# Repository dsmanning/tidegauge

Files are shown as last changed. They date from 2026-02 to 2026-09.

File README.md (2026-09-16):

# Remote Tide Gauge (Feather RP2040 + TTN)

This project builds a remote tide gauge using an Adafruit Feather RP2040 RFM, an RFM95 LoRa radio, and an HC-SR04 ultrasonic sensor.

The sensor is mounted at the top of a tube and measures water height inside the tube. The Feather samples once per minute, packages the reading, and sends it through LoRaWAN to The Things Network (TTN) via your local TTN gateway.

Current radio/uplink path is Arduino LMIC OTAA firmware in `arduino/ttn_otaa_lmic`.

## Hardware

- Adafruit Feather RP2040
- RFM95 LoRa radio module
- HC-SR04 ultrasonic module
- TTN gateway
- Development host: Raspberry Pi 5
- USB connection to Feather:
  - Mass storage device (for file transfer): `/dev/sda`
  - Serial console: `/dev/ttyACM0`

## Development approach

We use strict test-driven development (TDD):

1. Write a failing test first.
2. Run tests to confirm failure.
3. Implement the smallest code change to pass.
4. Re-run tests.
5. Refactor while keeping tests green.
6. Repeat in small increments.

Code is designed for testability:

- Hardware access is isolated behind interfaces/adapters.
- Core logic is pure and mockable.
- Time, I/O, and radio boundaries are injected dependencies.

## Data flow

1. Trigger measurement every 60 seconds.
2. Read distance from HC-SR04.
3. Convert distance to water height using calibration constants.
4. Build payload as signed millimeters (`int16`, big-endian).
5. Transmit payload through RFM95/LoRaWAN to TTN.
6. Log status/errors to serial for diagnostics.

## Tide Datum Calibration (Post-Install)

The device must support datum calibration after physical installation at the final site.

- Raw measurement from the ultrasonic sensor is distance from sensor-to-water surface.
- Tide height requires a site-specific datum offset that is not final until installation.
- The software should apply:
  - `tide_height = geometry_reference - measured_distance - datum_offset`
  - Where `geometry_reference` (sensor-to-reference geometry) and `datum_offset` are configurable calibration values.

Recommended calibration workflow:

1. Install and mechanically secure the sensor in final position.
2. Take one or more manual reference readings against known local tide datum.
3. Compute/update `datum_offset` (and `geometry_reference` if needed).
4. Persist calibration values in device configuration.
5. Verify reported tide height against reference observations.

TDD impact:

- Add tests first for calibration math and configuration handling.
- Verify behavior before calibration is set (safe defaults/error handling).
- Verify updated calibration changes only conversion output, not transport logic.
- Keep calibration logic in pure, testable code paths with hardware mocked.

## Testing strategy

- Host-side unit tests validate:
  - Distance-to-height conversion
  - Payload encoding
  - Scheduler behavior (1-minute cadence)
  - Error handling and retries
- Hardware integrations are wrapped so they can be replaced with mocks/fakes in tests.
- On-device validation is done only after host tests pass.

## Project status

The production path is Arduino LMIC. The older Python/CircuitPython modules are
retained for reference; their tests do not validate the deployed Arduino scheduler.
Firmware orchestration is in `arduino/ttn_otaa_lmic/src/app`, hardware adapters in
`src/adapters`, and injected contracts in `src/ports`. Pure payload/calibration
logic is in `measurement.h` and `tide_math.h`.

## Pi-to-Feather Workflow

Use this sequence for deployment and runtime verification from the Raspberry Pi host.

1. Run host tests:
   `python3 -m pytest -q`
2. Confirm device connectivity:
   `lsblk -f` and verify `/dev/sda` (mounted volume) plus `/dev/ttyACM0` (serial).
3. Compile Arduino firmware:
   - First copy/edit config:
     `cp -n arduino/ttn_otaa_lmic/config.example.h arduino/ttn_otaa_lmic/config.h`
   - Set `DEV_EUI_HEX`, `APP_EUI_HEX`, `APP_KEY_HEX`, `US915_SUBBAND`, `GEOMETRY_REFERENCE_M`, and `DATUM_OFFSET_M` in `arduino/ttn_otaa_lmic/config.h`.
   - `config.h` is git-ignored by design; keep real credentials only in that local file.
   `bash scripts/compile_firmware.sh --output-dir build/firmware`
   The build script explicitly selects US915/RFM95 and allocates **64 KB** of
   LittleFS flash for the join-nonce journal. The default board setting has no
   filesystem and cannot operate the persistent join allocator.
4. Upload Arduino firmware:
   Update the TTN decoder below first, then:
   `arduino-cli upload -b rp2040:rp2040:adafruit_feather_rfm:flash=8388608_65536 -p /dev/ttyACM0 --input-dir build/firmware arduino/ttn_otaa_lmic`
5. Monitor serial runtime logs on `/dev/ttyACM0` and verify a measurement/send cycle appears once per minute.
6. Confirm uplinks in TTN for the same time window as serial logs.

## Firmware Watchdog

The hardware watchdog is armed before startup waits and peripheral initialization.
It resets the RP2040 after **8 seconds** without a feed; unsupported delays above
8388 ms fail compilation. The prior 20-second setting was invalid for RP2040.
Ultrasonic acquisition now advances one pulse at a time (45 ms maximum blocking
wait); settling, sample gaps and temperature conversion are scheduled stages.
LMIC receives service between stages, and acquisition yields around radio deadlines.

The supervisor also detects failures that leave the CPU running: a measurement
cycle exceeding 30 seconds resets the sensor state, a second consecutive stall
reboots; a joined radio with no progress for 3 minutes restarts joining, and a
subsequent radio stall reboots. Joining receives a 30-minute progress deadline.
Deliberate retry backoff (1 minute increasing to 1 hour) does not cause reboots.
Normal join attempts count as local progress even when the gateway is offline.
Local transmit completion does not prove network reception.

Measurements start on a fixed 60-second schedule independent of radio joining.
The latest completed measurement replaces older unsent data; there is no historical
backfill. Invalid readings still produce a packet containing working fields.
Default quality requirements are at least 16 valid samples out of 64 and a
cluster of at least three. Physical echo bounds default to 0.02–6 m; customize
`TIDEGAUGE_MIN_DISTANCE_M` / `TIDEGAUGE_MAX_DISTANCE_M` in local configuration.
After three temperature failures the bus is rediscovered and reconfigured.

ADR owns transmit power while enabled; the configured 10 dBm value applies only
when ADR is disabled. LMIC link recovery is enabled. Verify link margin at the
installed location and calculate airtime for the actual data rate; sampling once
per minute need not imply that every network permits transmitting that often.

Validated toolchain: Arduino CLI 1.4.1, Arduino-Pico 5.5.0, MCCI LMIC 5.0.1,
OneWire 2.3.8, DallasTemperature 4.0.6. Host checks use pytest, g++, Node.js,
PyYAML and Jinja2 already present on the development host. Build/test commands
do not install dependencies. Physical acceptance procedures and remaining
limitations are in [docs/reliability-validation.md](docs/reliability-validation.md).

## TTN Credentials (Arduino LMIC)

Set OTAA credentials in `arduino/ttn_otaa_lmic/config.h`:

- `DEV_EUI_HEX`
- `APP_EUI_HEX`
- `APP_KEY_HEX`
- `US915_SUBBAND`: human numbering **1–8**, converted to LMIC **0–7**. Value `2`
  selects channels 8–15 (LMIC index 1). Confirm against the gateway frequency plan.

Invalid credential syntax disables radio operation while sampling continues.
Channel fallback visits every group and returns to the preferred group.

Join nonces are reserved in blocks of 32 in `/join-nonce.bin` before use, using
an atomic LittleFS replacement and read-back verification. Reboots skip unused
reserved nonces. Preserve this filesystem and its allocation when updating
firmware; never erase it for ordinary recovery. Only a completely blank allocated
region is formatted automatically. Missing allocation, corrupt storage, failed
writes, or exhausted 16-bit nonce space stop joins with a serial error, rather
than silently reusing nonces. These faults require maintenance, not reboot loops.
First migration from the old random-nonce firmware must be checked against TTN's
stored nonce history and configured LoRaWAN version. Do not disable replay
protection to make joins succeed; coordinate reprovisioning if necessary.

## TTN Payload Formatter

Use `ttn/uplink_decoder.js` as the TTN JavaScript uplink payload formatter.

Normal uplinks on FPort 1 retain the 10-byte payload:

- Bytes `0-1`: `tide_height_mm` (signed int16, big-endian)
- Bytes `2-3`: `raw_distance_mm` (unsigned uint16, big-endian)
- Bytes `4-5`: `battery_mv` (unsigned uint16, big-endian)
- Bytes `6-7`: `distance_stddev_mm` (unsigned uint16, big-endian)
- Bytes `8-9`: `temperature_centi_c` (signed int16, big-endian)

Invalid optional measurements use sentinel values so one failed sensor reading
does not block the whole uplink:

- signed invalid sentinel: `0x8000`
- unsigned invalid sentinel: `0xFFFF`

Battery now also uses `0xFFFF` for unavailable, decoded as `null`.
The first queued packet and every 15th thereafter attempt a diagnostic extension
on FPort 2: **26 bytes** total, with the same first 10 bytes. Deploy the new decoder
before the firmware. If the current data rate cannot carry the extension, the
radio sends the 10-byte measurement at that data rate; diagnostic details may
therefore be unavailable on a weak link.

| Bytes | Diagnostic field (big-endian) |
| --- | --- |
| 10 | Schema version: 1 |
| 11 | Fault bits: 0 height, 1 temperature, 2 battery, 3 echo stuck high |
| 12 | Reset reason: 0 other/power-on, 1 sensor stall, 2 radio stall, 3 watchdog/other watchdog reset |
| 13 | Firmware revision: 2 |
| 14–17 | Uptime seconds (continues across `millis()` rollover) |
| 18–19 | Recovery count since boot |
| 20–21 | Valid echo count, timeout count |
| 22–23 | Watchdog reset count retained across watchdog resets; clears on cold start |
| 24–25 | Measurement sequence modulo 65536 |

## Home Assistant Filtering

The optional Home Assistant configuration in `homeassistant/tide_gauge_filter.yaml`
adds a post-TTN filtering pipeline for the decoded tide-height sensor.

Its purpose is to clean occasional ultrasonic outliers while preserving the slow
water-level trend:

1. hold the last valid numeric reading
2. compute a 10-minute rolling median
3. reject remaining outlier values outside recent history
4. apply light low-pass smoothing

This filter runs in Home Assistant, not on the RP2040. It should be merged into
an existing Home Assistant configuration carefully if that installation already
has top-level `template:` or `sensor:` sections.

Add `homeassistant/tide_gauge_freshness.yaml` to track last packet, last valid
height, and last valid temperature separately. It requires the actual TTN uplink
MQTT topic bridged into Home Assistant's broker; replace the placeholder topic
and merge the template lists. No account connection is configured by this repo.
Stale indicators turn on after five minutes without the relevant report, even
if filtering retains an old value. Use `sensor.tide_height_current` for the
freshness-gated dashboard reading. The templates use the server's `received_at`
timestamp, not MQTT replay/arrival time. See the official
[MQTT trigger documentation](https://www.home-assistant.io/docs/automation/templating/)
and [template integration](https://www.home-assistant.io/integrations/template).

## Sensor Wiring And Calibration

### Payload compatibility

The TTN decoder accepts the deployed 10-byte measurement payload, the compact
11-byte session-marker payload, the earlier 12-byte sequence payload, and the
26-byte diagnostic payload produced by firmware revision 2. For 11-byte
payloads, byte 10 uses bit 7 as `session_start` and bits 0–6 as the rolling
sample sequence. For 12-byte payloads, bytes 10–11 contain the sequence as an
unsigned big-endian integer. Keep the decoder installed before changing the
firmware payload format.

### Electrical safety

The HC-SR04 is powered from 5V. Its ECHO output must pass through a level
shifter or resistor divider before reaching RP2040 D5; never connect a 5V ECHO
signal directly to the RP2040. The DS18B20 data line uses D9 with a 4.7k pullup
to 3.3V.

HC-SR04 pinout (Feather labels):

- `TRIG` -> `D6`
- `ECHO` -> `D5`
- `VCC` -> `5V`
- `GND` -> `GND`

Firmware calibration constants are in `arduino/ttn_otaa_lmic/config.h`:

- `DISTANCE_SCALE`
- `DISTANCE_OFFSET_M`
- `GEOMETRY_REFERENCE_M`
- `DATUM_OFFSET_M`

Conversion formula:
`corrected_distance_m = measured_distance_m * distance_scale + distance_offset_m`
`tide_height_m = geometry_reference_m - corrected_distance_m - datum_offset_m`

Important electrical note:
`HC-SR04 ECHO` is a 5V signal and must be level-shifted (or resistor-divided) before feeding RP2040 `D5` (3.3V-only input).

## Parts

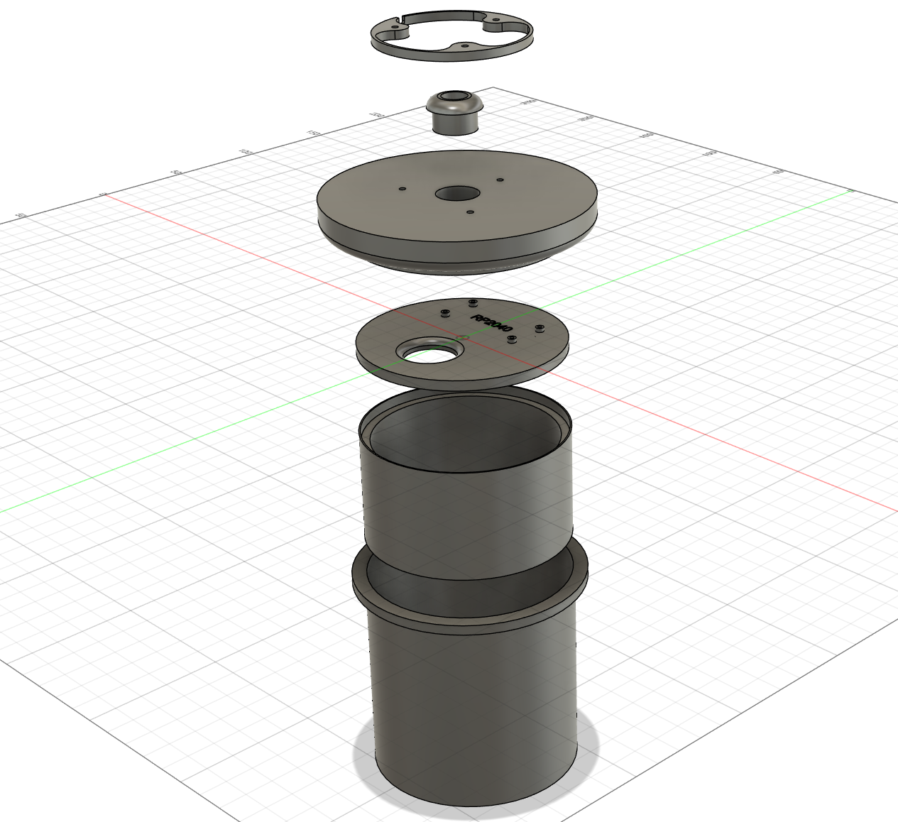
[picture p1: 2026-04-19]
stl/Tide Gauge - Assembly of 3D Printed Parts.png

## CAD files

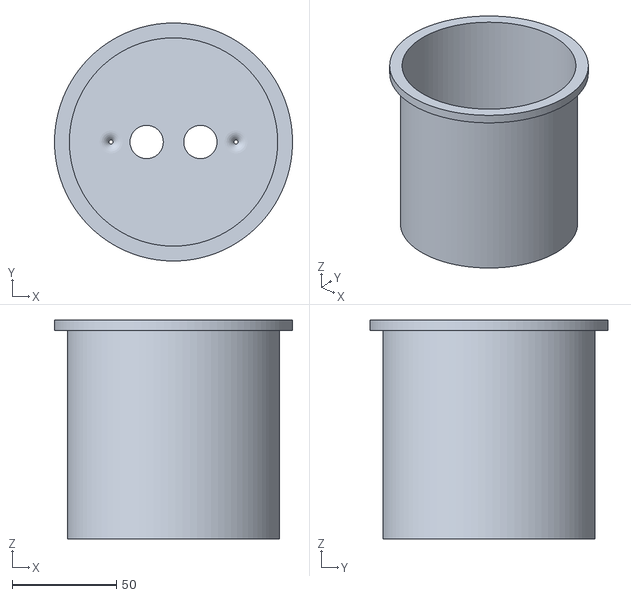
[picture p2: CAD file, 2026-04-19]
stl/Tide Gauge Mount - Outer Body - HC-SR04.stl
114.3 x 114.3 x 105.0

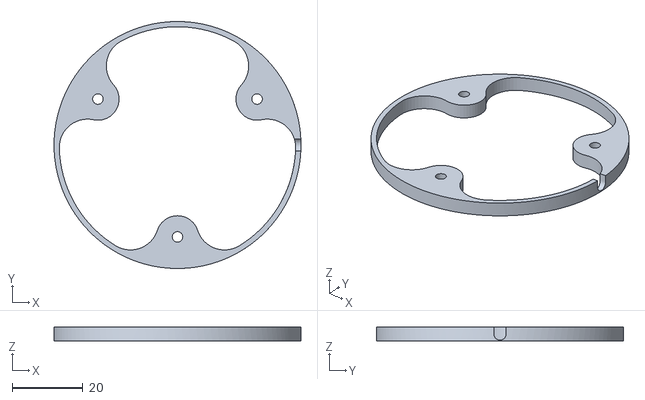
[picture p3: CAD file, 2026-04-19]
stl/Tide Gauge Mount - Top Ring - 10W.stl
70.0 x 70.0 x 4.00

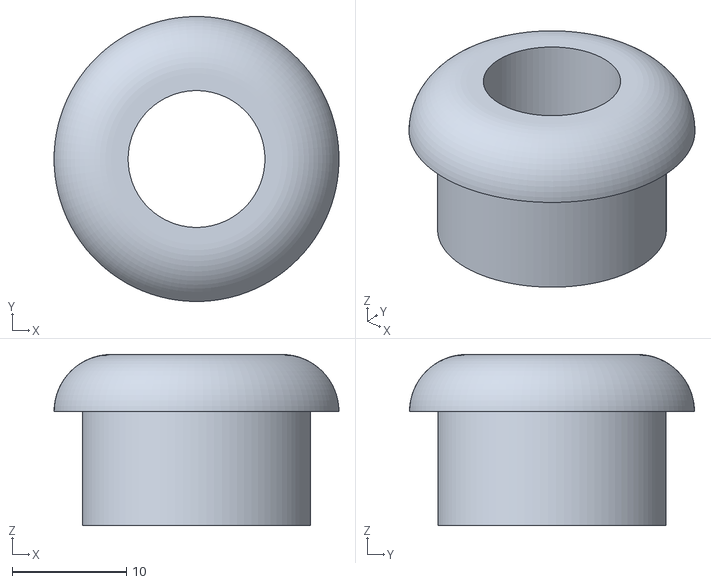
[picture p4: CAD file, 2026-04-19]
stl/Tide Gauge Mount - Top Plug.stl
25.0 x 25.0 x 15.0

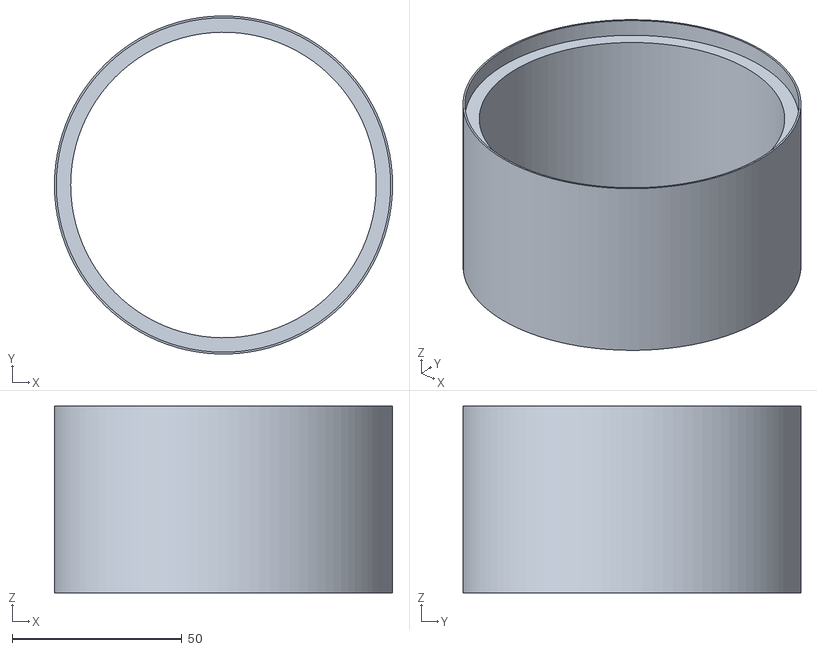
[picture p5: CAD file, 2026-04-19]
stl/Tide Gauge Mount - Bottom Support Ring.stl
99.6 x 99.6 x 55.0

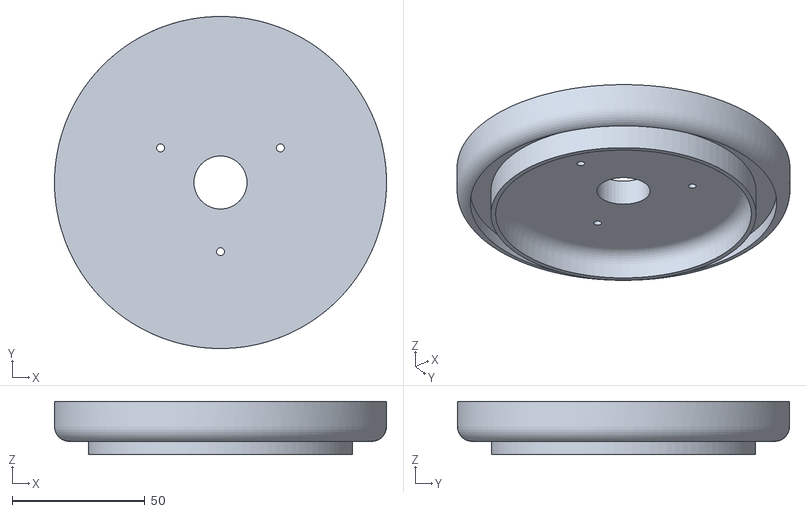
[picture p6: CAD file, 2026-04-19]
stl/Tide Gauge Mount - Top - 10W.stl
125.0 x 125.0 x 20.0

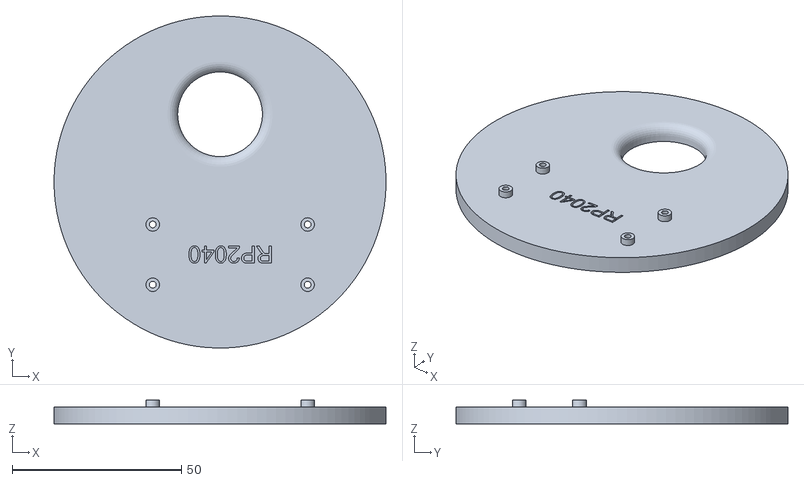
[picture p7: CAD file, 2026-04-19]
stl/Tide Gauge Mount - Middle Part.stl
98.0 x 98.0 x 7.00

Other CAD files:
stl/Tide Gauge Mount - Outer Body JSN-SR04T.stl

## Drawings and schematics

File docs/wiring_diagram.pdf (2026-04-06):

# Remote Tide Gauge Circuit Diagram

## Emitter

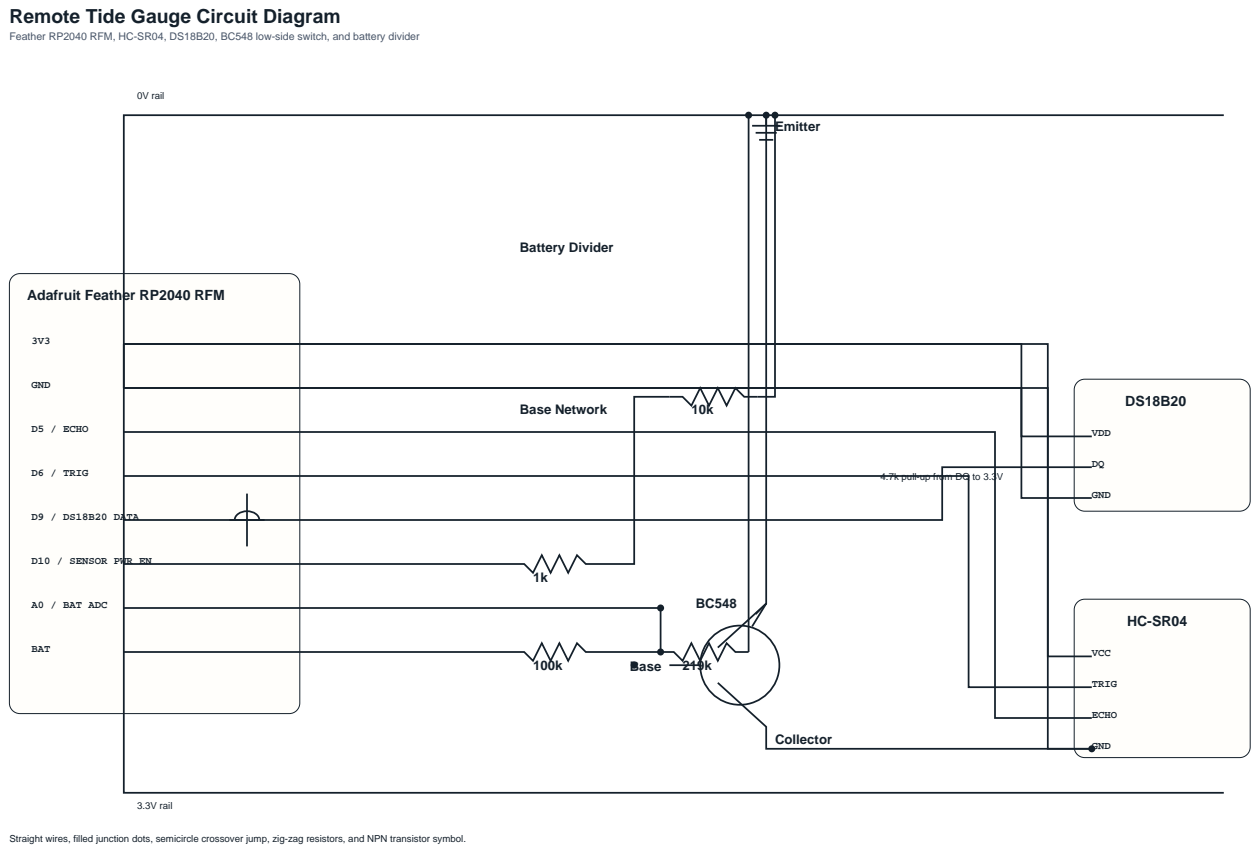
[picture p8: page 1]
GND; D5 / ECHO; D6 / TRIG; D9 / DS18B20 DATA; A0 / BAT ADC; BAT; VCC; TRIG; ECHO; VDD; 3.3V rail; 0V rail; Base Network; Base; Collector; Battery Divider

Feather RP2040 RFM, HC-SR04, DS18B20, BC548 low-side switch, and battery divider

Adafruit Feather RP2040 RFM

4.7k pull-up from DQ to 3.3V

D10 / SENSOR PWR EN

Straight wires, filled junction dots, semicircle crossover jump, zig-zag resistors, and NPN transistor symbol.

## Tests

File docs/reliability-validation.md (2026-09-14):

# Unattended-node acceptance

Host tests and a successful compile do not establish that a radio, sensor power
switch, supply, or enclosure will recover in the field. Complete these checks
on the real Feather before installing it somewhere inaccessible.

## Build and migration

Use `bash scripts/compile_firmware.sh --output-dir build/firmware` with the
versions recorded in README. This pins regional compilation flags for both C
and C++, rather than relying on edits inside an installed LMIC library.
Keep local `config.h`, binaries, and TTN credentials out of git.

Verify US915 group 2 means LMIC index 1 and matches the actual gateway channel
plan. Confirm TTN MAC/PHY settings match the installed LMIC version. Firmware
does not become LoRaWAN 1.0.4/1.1 merely by using persistent nonces.

Install the new TTN decoder before firmware revision 2. Reserve the documented
64 KB filesystem and preserve it on future uploads. On first migration, check
TTN join events for previously used/non-increasing DevNonce errors: the old
firmware used random nonces and this release cannot infer the server's history.
If necessary, plan credential/device reprovisioning before field installation.
Do not erase the journal or weaken replay checks as an unattended workaround.

## Fault-injection acceptance

| Test | Required observation |
| --- | --- |
| Cold boot without USB console | Joins and reports without waiting indefinitely for serial |
| MCU stall in an isolated test build | Hardware reset within about 8 seconds; diagnostic reset reason 3 |
| Suppressed TX-complete event in test build | Radio recovery after about 3 minutes; samples continue |
| Radio progress remains absent after recovery | Reboot after join grace period, with reason 2 |
| Gateway off for several hours, then restored | Bounded join retries; no rapid reboot loop; reports resume |
| Echo disconnected or held high | Invalid height, timeout/echo flags; temperature and battery still transmit |
| Temperature sensor absent at boot, then reattached | Discovery retry restores temperature within roughly four sample cycles |
| Power interrupted during a nonce reservation | Next boot never reuses a nonce emitted before interruption |
| Corrupt nonce file (bench copy only) | Joining stops with explicit storage error; no autoformat |
| Weak radio link / lowest data rate | Measurements continue even when diagnostic extension does not fit |
| No MQTT packets for five minutes | Link and data stale; dashboard current height becomes unavailable |
| Packets with invalid height but valid temperature | Link remains current; height becomes stale independently |

Run a minimum 72-hour soak with the final wiring, battery supply, sensors,
enclosure and antenna. Include gateway outage/recovery, repeated sensor faults,
and cold starts. Inspect TTN frame counters, join failures, uplink spacing,
diagnostic resets and sample quality. Host simulations cover clock rollover,
long outages and failure escalation, but do not replace these measurements.

## Electrical checks

Measure supply voltage during radio TX and sensor startup; a healthy unloaded
battery does not establish adequate transient supply margin. Confirm echo level
shifting and pull-ups, power-switch polarity, a safe sensor-off state during MCU
reset, and actual sensor rail discharge when switched off. Inspect moisture
protection and cable strain relief. Verify radio reset wiring.

If a fault survives MCU and radio reset, evaluate an independent supervisor
that cycles power to the entire node with controlled backoff. That is a hardware
change requiring bench validation; it is not supplied by firmware alone.

## Operational limits

Only the latest measurement is queued, not an outage history. Diagnostic packets
are unconfirmed and can be lost, particularly at low data rates. A local TX
completion proves the radio cycle ended, not gateway/cloud reception. Persistent
nonce ranges consume 32 values per cold/recovery boot at minimum and eventually
exhaust the 16-bit namespace; avoid periodic gratuitous rebooting and monitor
join failures. The stored reset counter is retained SRAM, not a lifetime count.

Compute daily airtime at the deployed data rate, including joins and status
packets. TTN Community's fair-use allowance is 30 seconds uplink airtime/day and
10 downlinks/day. A private gateway connected to the community network does not
remove that allowance. If necessary, keep minute sampling but batch or reduce
transmissions as a separately tested site policy. See
[TTN duty-cycle and fair-use guidance](https://www.thethingsnetwork.org/docs/lorawan/duty-cycle/).

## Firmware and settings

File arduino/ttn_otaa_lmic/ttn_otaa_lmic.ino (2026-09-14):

#include <Arduino.h>
#include <SPI.h>
#include <pico/time.h>
#include <hardware/watchdog.h>
#include <OneWire.h>
#include <DallasTemperature.h>
#include <lmic.h>
#include <hal/hal.h>
#if __has_include("config.h")
#include "config.h"
#else
#include "config.example.h"
#endif
#include "runtime_config.h"
#include "src/app/node_runtime.h"
#include "src/adapters/arduino_sensor.h"
#include "src/adapters/lmic_radio.h"
#include "src/adapters/nonce_storage.h"

static_assert(tg_config::US915_SUBBAND >= 1 && tg_config::US915_SUBBAND <= 8, "Subband must be 1..8");
static_assert(tg_config::ULTRASONIC_SAMPLE_COUNT >= 3 && tg_config::ULTRASONIC_SAMPLE_COUNT <= 100, "Sample count must be 3..100");
static_assert(tg_config::ULTRASONIC_TIMEOUT_US > 0 && tg_config::ULTRASONIC_TIMEOUT_US <= 45000, "Echo deadline must be <=45ms");
static_assert(tg_config::ULTRASONIC_POWER_SETTLE_MS <= 5000 && tg_config::ULTRASONIC_INTERSAMPLE_DELAY_MS <= 100, "Sensor cycle must fit 30s deadline");
static_assert(tg_config::DS18B20_RESOLUTION_BITS >= 9 && tg_config::DS18B20_RESOLUTION_BITS <= 12, "DS18B20 resolution must be 9..12");
static_assert(tg_config::IDLE_LOOP_SLEEP_MS <= 10, "LMIC must be serviced frequently");
static_assert(tg_config::RAPID_DIAGNOSTIC_INTERVAL_S > 0, "Sampling interval must be positive");
static_assert(TIDEGAUGE_MIN_DISTANCE_M > 0 && TIDEGAUGE_MAX_DISTANCE_M > TIDEGAUGE_MIN_DISTANCE_M, "Invalid sensor range");

static uint8_t APPEUI[8], DEVEUI[8], APPKEY[16];
static const int HCSR04_TRIG_PIN = D6;
static const int HCSR04_ECHO_PIN = D5;
static const int HCSR04_POWER_ENABLE_PIN = tg_config::ULTRASONIC_POWER_ENABLE_PIN;
static const int BATTERY_ADC_PIN = 26;
static const float BATTERY_DIVIDER_RATIO = 1.545f;
static OneWire g_one_wire(tg_config::DS18B20_DATA_PIN);
static DallasTemperature g_temperature_sensors(&g_one_wire);
static tidegauge::SubbandFallback g_subband_fallback(tg_config::US915_SUBBAND);
static osjob_t sendjob;

void os_getArtEui(u1_t* buf) {memcpy(buf,APPEUI,8);}
void os_getDevEui(u1_t* buf) {memcpy(buf,DEVEUI,8);}
void os_getDevKey(u1_t* buf) {memcpy(buf,APPKEY,16);}
const lmic_pinmap lmic_pins = {
    .nss=PIN_RFM_CS, .rxtx=LMIC_UNUSED_PIN, .rst=PIN_RFM_RST,
    .dio={PIN_RFM_DIO0,PIN_RFM_DIO1,PIN_RFM_DIO2},
};

class ArduinoClock : public tidegauge::ClockPort {
    uint32_t now_ms() override {return millis();}
};
class HardwareWatchdog : public tidegauge::WatchdogPort {
public:
    void feed() override {watchdog_update();}
    void reboot(uint8_t reason) override {
        watchdog_hw->scratch[2]=reason;
        watchdog_reboot(0,0,0);
        while(true) {} // Do not feed after requesting recovery.
    }
};
static ArduinoClock g_clock;
static HardwareWatchdog g_watchdog;
static tidegauge::LittleFsNonceStorage g_storage;
static tidegauge::JoinNonce g_nonce(g_storage);
static tidegauge::LmicRadio g_radio(g_clock,g_nonce,g_subband_fallback,
    tg_config::LORA_ADR_ENABLED,tg_config::LORA_UPLINK_TX_POWER_DBM);
static tidegauge::ArduinoSensor g_sensor_hardware(g_temperature_sensors,
    HCSR04_TRIG_PIN,HCSR04_ECHO_PIN,HCSR04_POWER_ENABLE_PIN,BATTERY_ADC_PIN,
    BATTERY_DIVIDER_RATIO,tg_config::ULTRASONIC_TIMEOUT_US,tg_config::DS18B20_RESOLUTION_BITS);

static tidegauge::SensorSettings sensor_settings() {
    tidegauge::SensorSettings s;
    s.samples=tg_config::ULTRASONIC_SAMPLE_COUNT;
    s.minimum_valid=s.samples/4>3 ? s.samples/4 : 3;
    s.settle_ms=HCSR04_POWER_ENABLE_PIN>=0 ? tg_config::ULTRASONIC_POWER_SETTLE_MS : 0;
    s.gap_ms=tg_config::ULTRASONIC_INTERSAMPLE_DELAY_MS;
    s.speed=tg_config::SPEED_OF_SOUND_M_PER_US;
    s.scale=tg_config::DISTANCE_SCALE; s.offset=tg_config::DISTANCE_OFFSET_M;
    s.reference=tg_config::GEOMETRY_REFERENCE_M; s.datum=tg_config::DATUM_OFFSET_M;
    s.min_distance=TIDEGAUGE_MIN_DISTANCE_M; s.max_distance=TIDEGAUGE_MAX_DISTANCE_M;
    return s;
}
static tidegauge::SensorCycle g_sensor(g_sensor_hardware,sensor_settings());
static tidegauge::NodeRuntime g_node(g_clock,g_sensor,g_radio,g_watchdog,
    tg_config::RAPID_DIAGNOSTIC_MODE ? tg_config::RAPID_DIAGNOSTIC_INTERVAL_S*1000 : 60000,
    tg_config::RAPID_DIAGNOSTIC_MODE);

static bool hex_to_bytes(const char* hex,uint8_t* out,size_t count) {
    if(strlen(hex)!=count*2) return false;
    for(size_t i=0;i<count;++i) {
        uint8_t value=0;
        for(unsigned j=0;j<2;++j) {
            const char c=hex[i*2+j];
            const int digit=c>='0' && c<='9' ? c-'0' :
                c>='a' && c<='f' ? c-'a'+10 : c>='A' && c<='F' ? c-'A'+10 : -1;
            if(digit<0) return false;
            value=static_cast<uint8_t>((value<<4)|digit);
        }
        out[i]=value;
    }
    return true;
}
static void reverse_bytes(uint8_t* bytes,size_t size) {
    for(size_t i=0;i<size/2;++i) {uint8_t b=bytes[i]; bytes[i]=bytes[size-1-i]; bytes[size-1-i]=b;}
}

// Never autoformat a damaged filesystem: losing the nonce journal permits reuse.
// Formatting is allowed only on a completely erased, allocated FS region.
extern uint8_t _FS_start, _FS_end;
static bool mount_nonce_storage() {
    const uintptr_t start=reinterpret_cast<uintptr_t>(&_FS_start);
    const uintptr_t end=reinterpret_cast<uintptr_t>(&_FS_end);
    if(end<=start || end-start<65536) return false;
    LittleFS.setConfig(LittleFSConfig(false));
    if(LittleFS.begin()) return true;
    for(uintptr_t address=start;address<end;++address) {
        if(*reinterpret_cast<const uint8_t*>(address)!=0xff) return false;
    }
    return LittleFS.format() && LittleFS.begin();
}

static void do_send(osjob_t*) {
    g_node.tick();
    static uint32_t logged=0;
    if(logged!=g_node.measurements) {
        logged=g_node.measurements;
        // Logging is best-effort and only after a completed measurement.
        if(Serial && Serial.availableForWrite()>=48) {
            Serial.print("MEASURE: height="); Serial.print(g_node.latest.height,3);
            Serial.print(" temperature_c="); Serial.println(g_node.latest.temperature,2);
        }
    }
}
void onEvent(ev_t event) {
    g_radio.on_event(event);
    if(Serial && Serial.availableForWrite()>=32) {
        Serial.print("LMIC event="); Serial.println(static_cast<unsigned>(event));
    }
}

void setup() {
    const bool watchdog_boot=watchdog_caused_reboot();
    const uint32_t magic=0x54474432;
    if(watchdog_boot && watchdog_hw->scratch[0]==magic) {
        g_node.watchdog_boots=static_cast<uint16_t>(watchdog_hw->scratch[1]+1);
        g_node.reset_reason=watchdog_hw->scratch[2] ? watchdog_hw->scratch[2] : 3;
    } else {
        g_node.watchdog_boots=watchdog_boot ? 1 : 0;
        g_node.reset_reason=watchdog_boot ? 3 : 0;
    }
    watchdog_hw->scratch[0]=magic;
    watchdog_hw->scratch[1]=g_node.watchdog_boots;
    watchdog_hw->scratch[2]=0;
    watchdog_enable(TIDEGAUGE_WATCHDOG_TIMEOUT_MS, true);
    Serial.begin(115200);
    while (!Serial && millis()<3000) {}
    if(watchdog_boot) Serial.println("WATCHDOG: reboot detected");
    Serial.println("Tide gauge firmware 2 starting");

    pinMode(HCSR04_TRIG_PIN,OUTPUT); pinMode(HCSR04_ECHO_PIN,INPUT);
    if(HCSR04_POWER_ENABLE_PIN>=0) pinMode(HCSR04_POWER_ENABLE_PIN, OUTPUT);
    g_sensor.reset(); digitalWrite(HCSR04_TRIG_PIN,LOW); analogReadResolution(12);
    watchdog_update();
    const bool credentials_ok=hex_to_bytes(tg_config::APP_EUI_HEX,APPEUI,sizeof(APPEUI)) &&
        hex_to_bytes(tg_config::DEV_EUI_HEX,DEVEUI,sizeof(DEVEUI)) &&
        hex_to_bytes(tg_config::APP_KEY_HEX,APPKEY,sizeof(APPKEY));
    if(!credentials_ok) {
        Serial.println("Invalid credentials: radio disabled; sampling continues");
    }
    reverse_bytes(APPEUI,sizeof(APPEUI)); reverse_bytes(DEVEUI,sizeof(DEVEUI));
    if (tg_config::RAPID_DIAGNOSTIC_MODE) {
        Serial.println("DIAG: skipping LoRa join");
        do_send(&sendjob);
        return;
    }
    g_storage.set_ready(credentials_ok && mount_nonce_storage());
    watchdog_update();
    os_init();
    watchdog_update();
    g_radio.begin();
}

void loop() {
    if(!tg_config::RAPID_DIAGNOSTIC_MODE) {
        g_radio.service();
        os_runloop_once();
    }
    do_send(&sendjob);
    static bool storage_error_logged=false;
    if(g_radio.storage_failed() && !storage_error_logged && Serial) {
        Serial.println("NONCE: storage unavailable/corrupt/exhausted; radio disabled");
        storage_error_logged=true;
    }
    sleep_ms(tg_config::IDLE_LOOP_SLEEP_MS);
}

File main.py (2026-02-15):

from tidegauge.main import run_main


TRIGGER_PIN_ID = 6
ECHO_PIN_ID = 5
CALIBRATION_PATH = "/calibration.json"
MEASUREMENT_INTERVAL_S = 60
MAX_SEND_ATTEMPTS = 3


def create_lora_client(
    *,
    driver_factory=None,
    credentials_loader=None,
):
    """Return configured LoRaWAN client for the board."""
    from tidegauge.adapters.lorawan_client import LoRaWanClientAdapter

    if driver_factory is None:
        from tidegauge.adapters.feather_lorawan import create_feather_lorawan_driver

        driver_factory = create_feather_lorawan_driver

    if credentials_loader is None:
        from tidegauge.ttn_credentials import load_ttn_credentials

        credentials_loader = load_ttn_credentials

    credentials = credentials_loader()
    return LoRaWanClientAdapter(driver=driver_factory(credentials=credentials))


def main() -> int:
    import board
    import digitalio
    import time
    from tidegauge.adapters.circuitpython_compat import (
        CircuitPythonTimeModule,
        create_machine_compat_module,
    )

    machine_module = create_machine_compat_module(
        board_module=board,
        digitalio_module=digitalio,
    )
    time_module = CircuitPythonTimeModule(time_module=time)

    return run_main(
        machine_module=machine_module,
        time_module=time_module,
        lora_client=create_lora_client(),
        trigger_pin_id=TRIGGER_PIN_ID,
        echo_pin_id=ECHO_PIN_ID,
        calibration_path=CALIBRATION_PATH,
        measurement_interval_s=MEASUREMENT_INTERVAL_S,
        max_send_attempts=MAX_SEND_ATTEMPTS,
    )


if __name__ == "__main__":
    main()

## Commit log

2026-02-15 Document post-install tide datum calibration in README
2026-02-15 Add initial tide-height calibration function with test
2026-02-15 Validate ultrasonic distance while allowing negative tide height
2026-02-15 Add calibration config model with explicit uncalibrated state
2026-02-15 Add TTN payload encoder for signed millimeter tide height
2026-02-15 Add sensor/radio port contracts with fake adapters
2026-02-15 Add measurement pipeline from sensor read to radio send
2026-02-15 Track Beads project state and issue history
2026-02-15 Update Beads issue ledger after completing backlog
2026-02-15 Update Beads ledger for runtime adapter completion
2026-02-15 Add ultrasonic adapter for echo-duration readers
2026-02-15 Update Beads ledger after ultrasonic increments
2026-02-15 Add JSON calibration persistence store
2026-02-15 Update Beads ledger after calibration store
2026-02-15 Add runtime loop with persisted calibration handling
2026-02-15 Update Beads ledger after runtime loop
2026-02-15 Update Beads ledger after HC-SR04 pulse reader
2026-02-15 Add RFM95 radio adapter with send error handling
    [radio.py]
2026-02-15 Update Beads ledger after radio adapter
2026-02-15 Update Beads ledger after runtime resilience
2026-02-15 Update Beads ledger after retry policy
2026-02-15 Update Beads ledger after hardware factory
2026-02-15 Add board entrypoint orchestration and main runner
2026-02-15 Update Beads ledger after board entrypoint
2026-02-15 Update Beads ledger after LoRaWAN client adapter
2026-02-15 Add install-time calibration update helper
2026-02-15 Update Beads ledger after calibration update helper
2026-02-15 Update Beads ledger after deployment helpers
2026-02-15 Update Beads ledger after deploy CLI
2026-02-15 Support string calibration paths for runtime compatibility
2026-02-15 Update Beads ledger after calibration path compatibility
2026-02-15 Add install-time calibration setup CLI
2026-02-15 Update Beads ledger after calibration CLI
2026-02-15 Migrate runtime to CircuitPython/Arduino LMIC with sanitized config handling
2026-02-15 Add tide+distance+battery payload and TTN decoder
2026-02-16 Improve ultrasonic robustness and subband fallback workflow
2026-04-06 Add furthest-cluster ultrasonic selection
2026-04-06 Add wiring diagram assets
2026-04-12 Create STL folder
2026-04-12 Add Tide Gauge Mount - Middle Part STL file
    [Tide Gauge Mount - Middle Part.stl]
2026-04-12 Add Tide Gauge Mount - Outer Body JSN-SR04T file
    [Tide Gauge Mount - Outer Body JSN-SR04T.stl]
2026-04-19 Add tide gauge filtering pipeline configuration
    This configuration file sets up a tide gauge filtering pipeline for Home Assistant, including templates and sensors for processing tide height readings.
2026-04-19 Document Home Assistant tide filter
2026-04-19 Update README for current payload and filtering
2026-09-16 Port diagnostics compatibility onto current firmware
